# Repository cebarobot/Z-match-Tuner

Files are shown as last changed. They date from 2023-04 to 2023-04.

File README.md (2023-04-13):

# Z-match Tuner
> An open source Z-match Tuner for QRP  
> 一个开源的用于 QRP 的 Z-match 天调



## File List 文件列表
* `Z-match manual.pdf` 中文说明书
* `Z-match chematic.pdf ` 原理图
* `z-match-2.zip` KiCad 工程文件
* `z-match-2-gerber.zip` Gerber 制板文件
* `z-match panel.eprj` 前后面板的 LCEDA 工程文件

## License
MIT LICENSE

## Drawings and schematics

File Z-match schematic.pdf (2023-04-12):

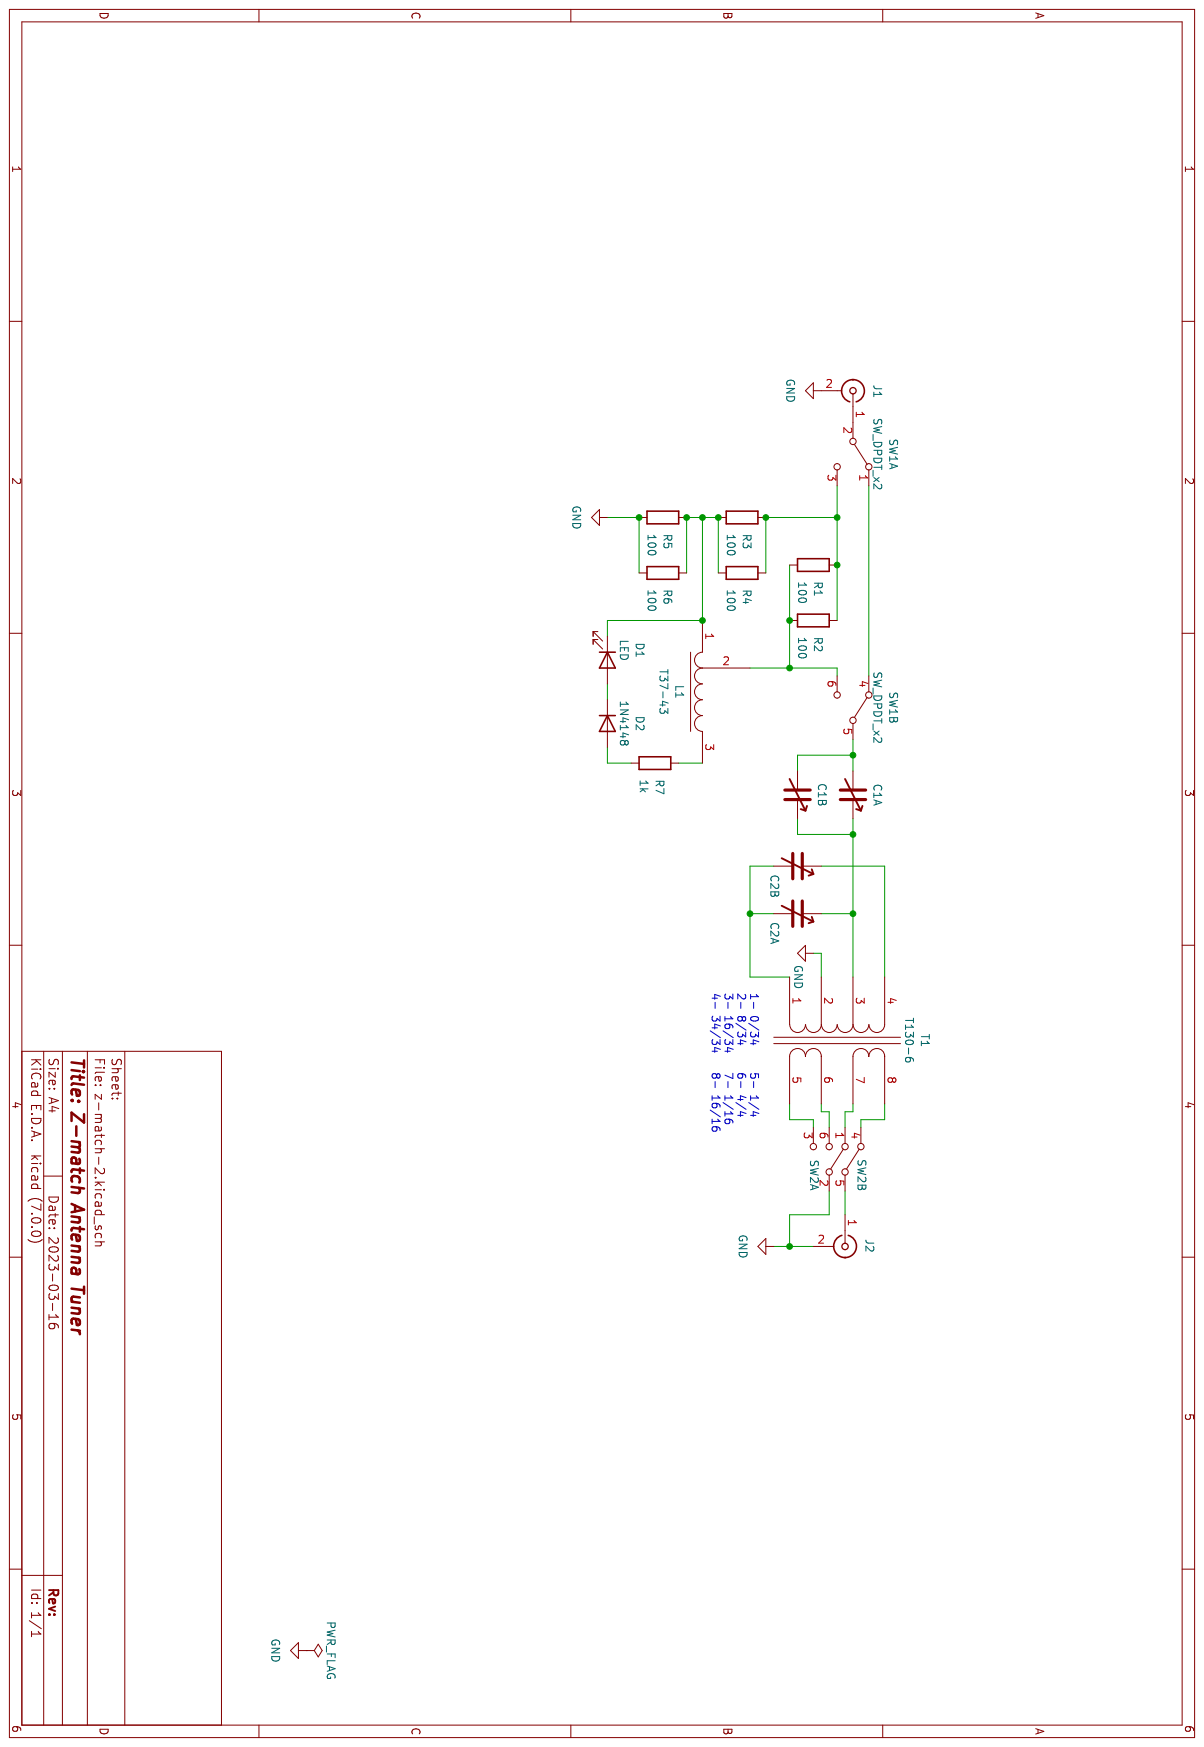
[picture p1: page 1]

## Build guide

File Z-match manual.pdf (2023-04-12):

Z-Match 套件安装使用手册

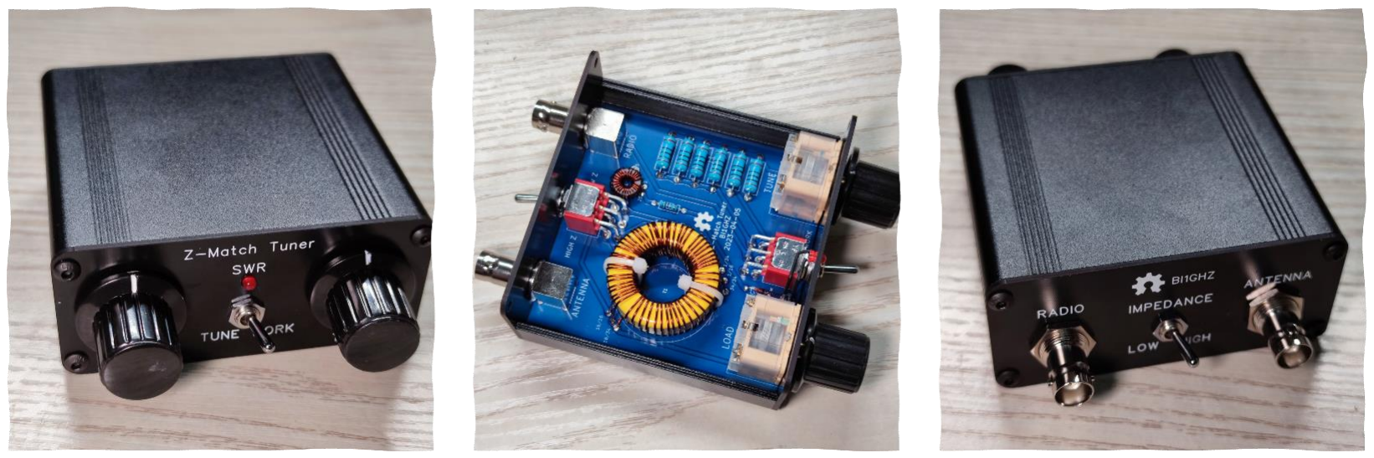
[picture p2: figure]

1 / 9

BI1GHZ 2023-04-13

### 零件表

检查 | 名称 | 数量 | 位号
| 可变电容 BM-443BF | 2 | C1, C2
| 加长杆 13mm | 2
| 螺丝 银色 圆头十字 M2.5×15mm | 2
| 螺丝 银色 沉头十字 M2.5×3 | 4
| 旋钮帽 KYP25-18-6 | 2
| 钮子开关 MT-0-202-A003-M003-RS | 2 | SW1, SW2
| 射频连接器 BNC-KWE 50R | 2 | J1, J2
| 电阻 1W 1% 100Ω | 6 | R1-6
| 电阻 1/4W 1% 1kΩ | 1 | R7
| 发光二极管 红色 3mm 长脚 | 1 | D1
| 二极管 1N4148 直插 | 1 | D2
| 环形铁氧体 FT37-43 | 1 | L1
| 环形铁氧体 T130-6 | 1 | L2
| 热缩管 Φ0.6 6cm | 1
| 扎带 3×80 | 2
| 漆包线 直径 0.4mm 长 60cm | 1
| 漆包线 直径 0.6mm 长 30cm | 1
| 漆包线 直径 0.6mm 长 50cm | 2
| 漆包线 直径 0.6mm 长 90cm | 1
| 漆包线 直径 0.6mm 长 100cm | 1
| PCB 蓝色 | 1
| 面板 FR-4 材质 黑色 88×38mm | 1 套
| 面板 铝合金 黑色 88×38mm | 1 套
| 机箱 铝合金 黑色 88×38×80mm | 1 套
| 螺丝 黑色 圆头内六角 M3×6 | 8
| 螺丝 黑色 沉头内六角 M3×6 | 8
| 简易套筒 10×55mm | 1

### 安装过程

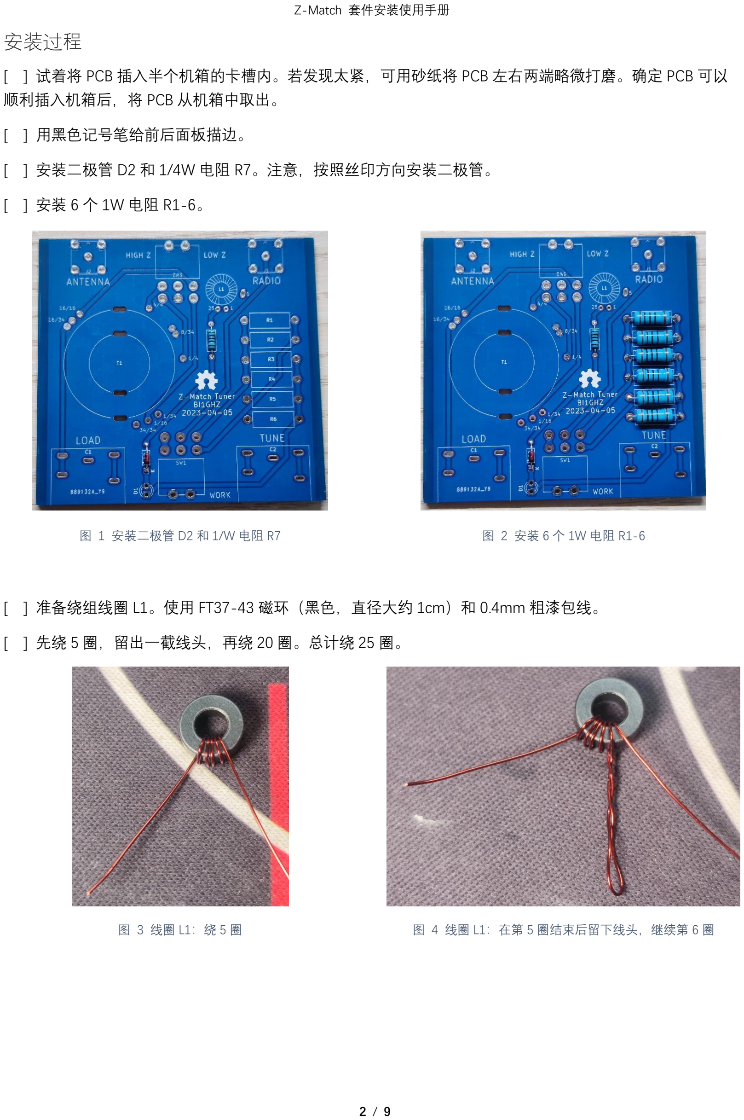
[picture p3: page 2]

2 / 9

[ ] 试着将 PCB 插入半个机箱的卡槽内。若发现太紧，可用砂纸将 PCB 左右两端略微打磨。确定 PCB 可以 顺利插入机箱后，将 PCB 从机箱中取出。

[ ] 用黑色记号笔给前后面板描边。

[ ] 安装二极管 D2 和 1/4W 电阻 R7。注意，按照丝印方向安装二极管。

[ ] 安装 6 个 1W 电阻 R1-6。

图 1 安装二极管 D2 和 1/W 电阻 R7 | 图 2 安装 6 个 1W 电阻 R1-6

[ ] 准备绕组线圈 L1。使用 FT37-43 磁环（黑色，直径大约 1cm）和 0.4mm 粗漆包线。

[ ] 先绕 5 圈，留出一截线头，再绕 20 圈。总计绕 25 圈。

图 3 线圈 L1：绕 5 圈 | 图 4 线圈 L1：在第 5 圈结束后留下线头，继续第 6 圈

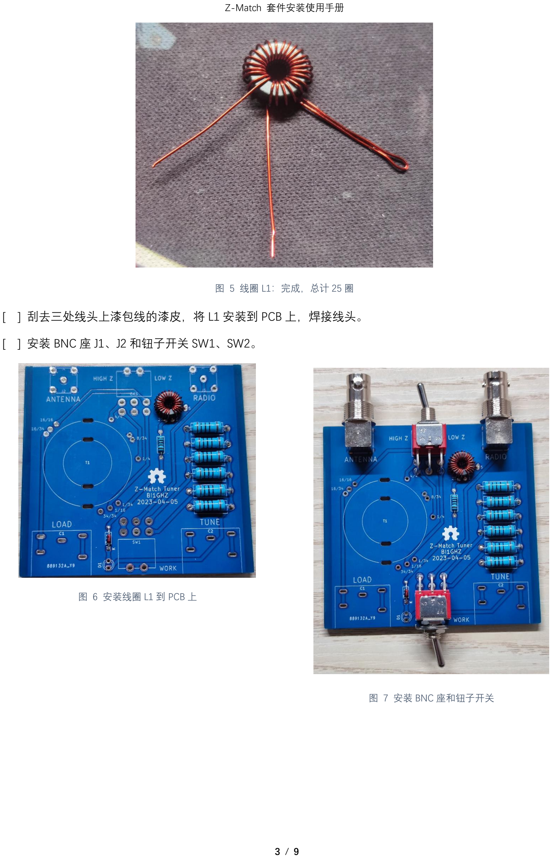
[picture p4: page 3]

3 / 9

图 5 线圈 L1：完成，总计 25 圈

[ ] 刮去三处线头上漆包线的漆皮，将 L1 安装到 PCB 上，焊接线头。

[ ] 安装 BNC 座 J1、J2 和钮子开关 SW1、SW2。

图 6 安装线圈 L1 到 PCB 上

图 7 安装 BNC 座和钮子开关

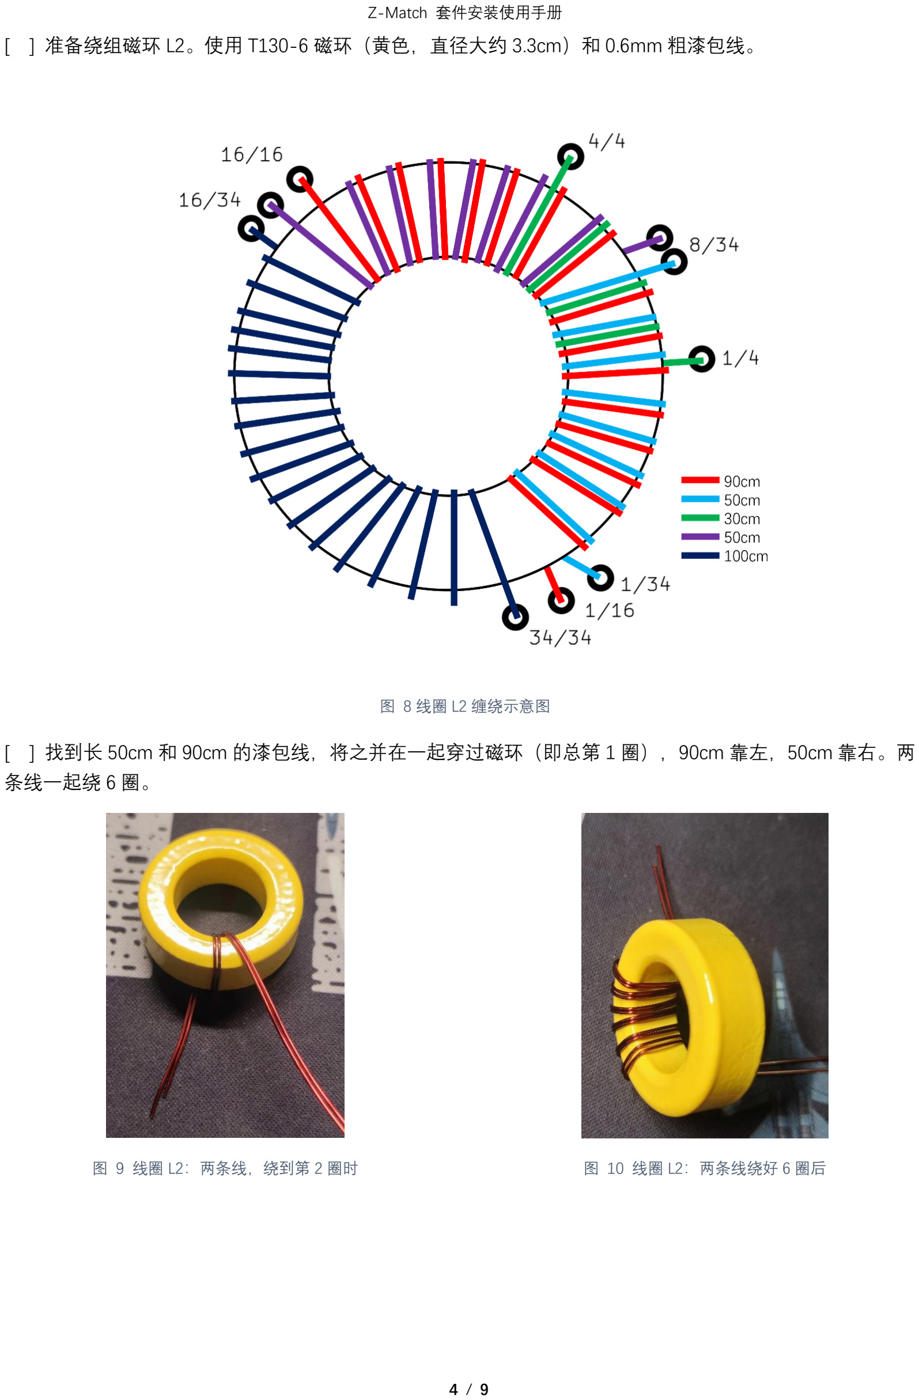
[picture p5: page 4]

4 / 9

[ ] 准备绕组磁环 L2。使用 T130-6 磁环（黄色，直径大约 3.3cm）和 0.6mm 粗漆包线。

图 8 线圈 L2 缠绕示意图

[ ] 找到长 50cm 和 90cm 的漆包线，将之并在一起穿过磁环（即总第 1 圈），90cm 靠左，50cm 靠右。两 条线一起绕 6 圈。

图 9 线圈 L2：两条线，绕到第 2 圈时 | 图 10 线圈 L2：两条线绕好 6 圈后

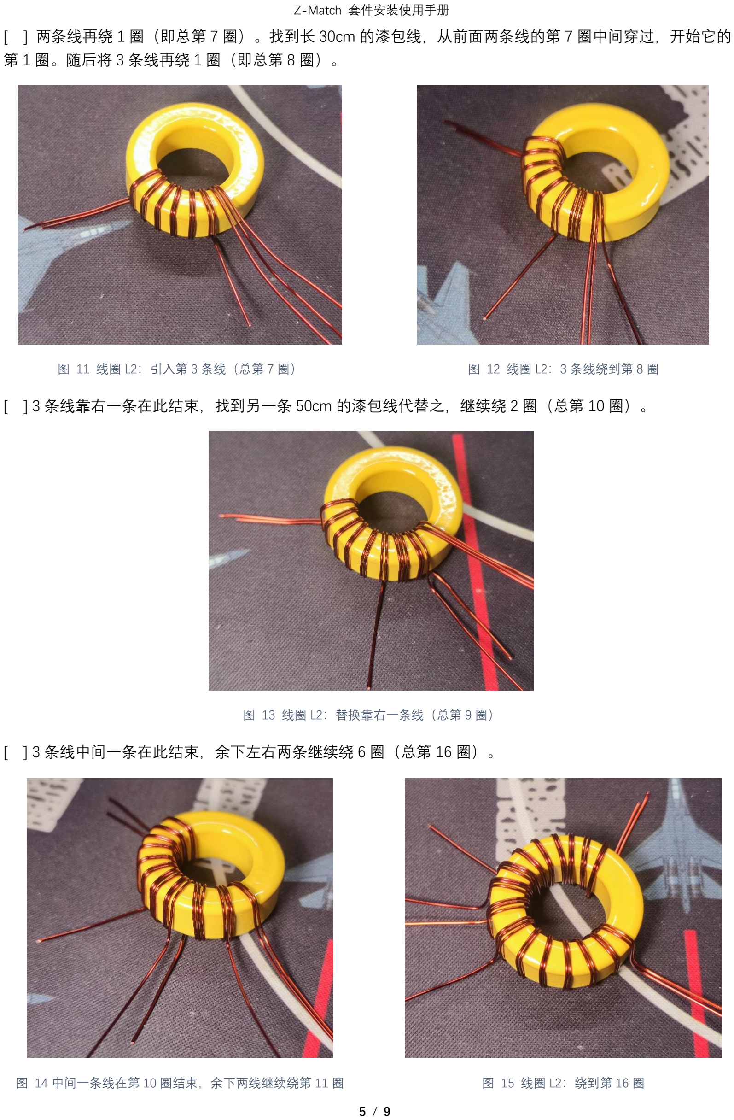
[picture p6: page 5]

5 / 9

[ ] 两条线再绕 1 圈（即总第 7 圈）。找到长 30cm 的漆包线，从前面两条线的第 7 圈中间穿过，开始它的 第 1 圈。随后将 3 条线再绕 1 圈（即总第 8 圈）。

图 11 线圈 L2：引入第 3 条线（总第 7 圈） | 图 12 线圈 L2：3 条线绕到第 8 圈

[ ] 3 条线靠右一条在此结束，找到另一条 50cm 的漆包线代替之，继续绕 2 圈（总第 10 圈）。

图 13 线圈 L2：替换靠右一条线（总第 9 圈）

[ ] 3 条线中间一条在此结束，余下左右两条继续绕 6 圈（总第 16 圈）。

图 14 中间一条线在第 10 圈结束，余下两线继续绕第 11 圈 | 图 15 线圈 L2：绕到第 16 圈

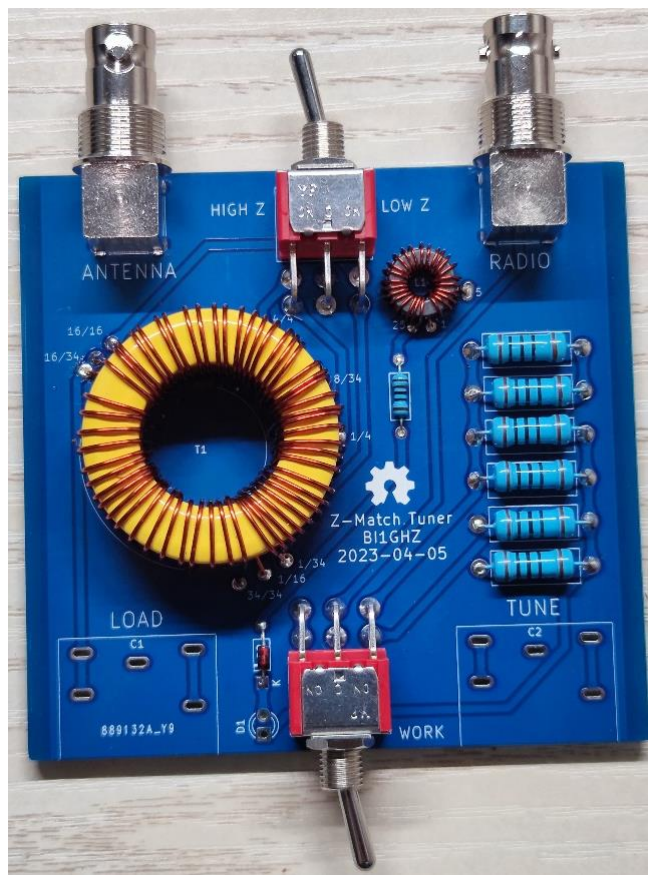
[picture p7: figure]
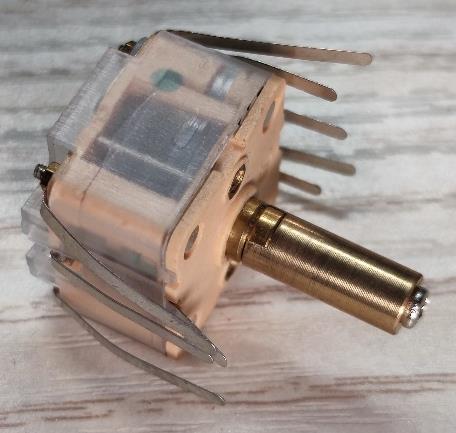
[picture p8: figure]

6 / 9

[ ] 2 条线均在此结束。找到 100cm 的漆包线，从此处开始绕 18 圈。

[ ] 刮去线头上漆包线的漆皮。将线头长度按逆时针或顺时针剪成阶梯状，以方便插入 PCB。

注意！在将 L2 安装到 PCB 前，务必进行目视检查，确保没有漆包线跨越缠绕；务必进行通铃检查，确保漆 包线头的顺序符合预期。

[ ] 将 L2 安装到 PCB 上，焊接接头。

图 16 将绕好的 L2 焊接到 PCB 上

[ ] 用扎带穿过安装孔，将磁环 L2 固定。

[ ] 将延长轴用 M2.5×12 螺丝固定到可调电容上。

图 17 安装好延长轴

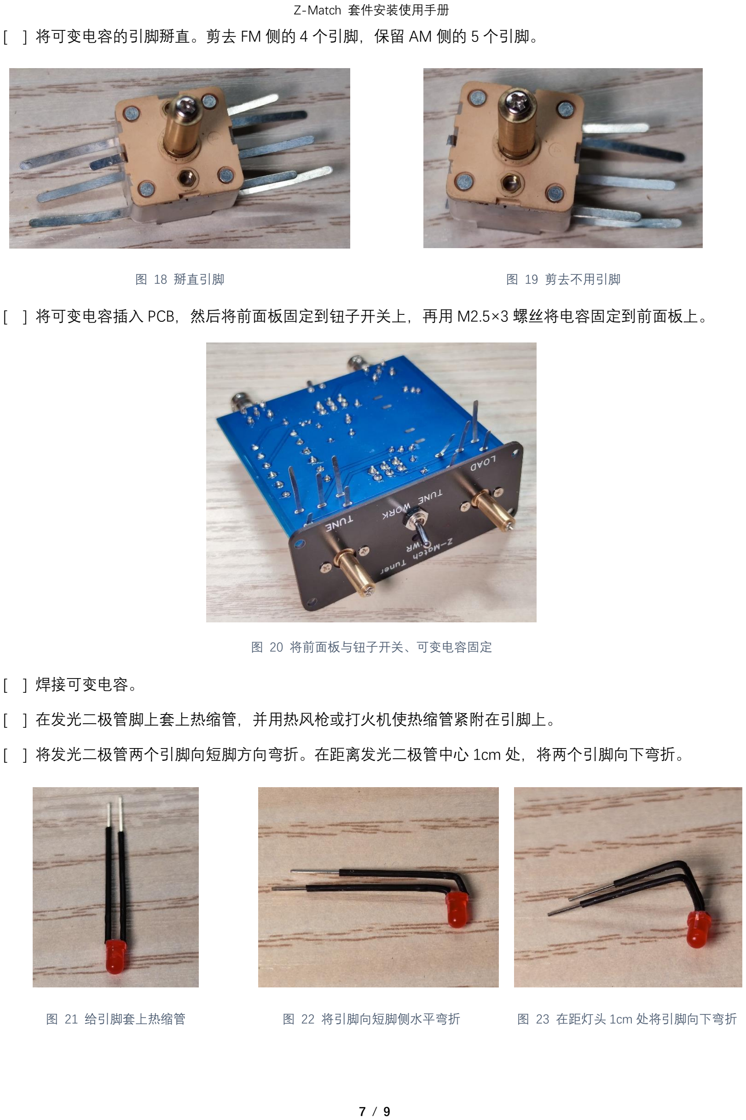
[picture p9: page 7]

7 / 9

[ ] 将可变电容的引脚掰直。剪去 FM 侧的 4 个引脚，保留 AM 侧的 5 个引脚。

图 18 掰直引脚 | 图 19 剪去不用引脚

[ ] 将可变电容插入 PCB，然后将前面板固定到钮子开关上，再用 M2.5×3 螺丝将电容固定到前面板上。

图 20 将前面板与钮子开关、可变电容固定

[ ] 焊接可变电容。

[ ] 在发光二极管脚上套上热缩管，并用热风枪或打火机使热缩管紧附在引脚上。

[ ] 将发光二极管两个引脚向短脚方向弯折。在距离发光二极管中心 1cm 处，将两个引脚向下弯折。

图 21 给引脚套上热缩管 | 图 22 将引脚向短脚侧水平弯折 | 图 23 在距灯头 1cm 处将引脚向下弯折

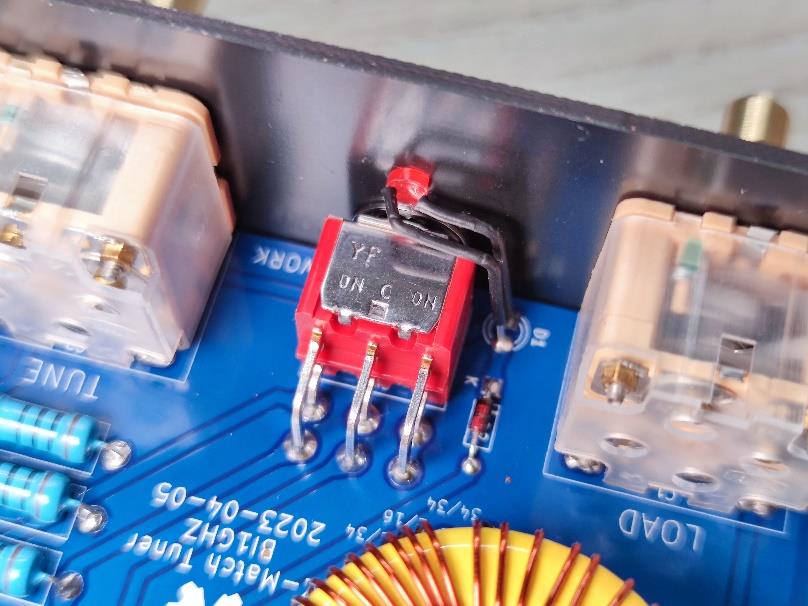
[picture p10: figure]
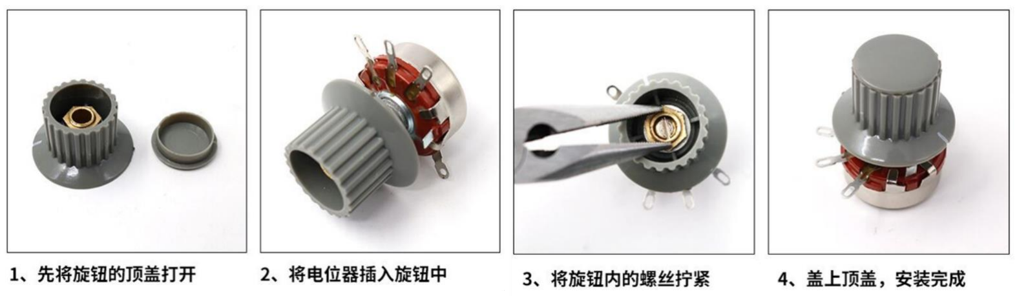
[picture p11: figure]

8 / 9

[ ] 将发光二极管穿过前面板上的洞，并焊接到 PCB 上。注意，短脚对方形焊盘。

图 24 安装好的 LED 示意

[ ] 将 PCB（和前面板）插入半个机箱中，将后面板、另半个机箱安装到位。将前后面板用 M3×6 圆头内六 角螺丝固定到机箱上，并将钮子开关、BNC 插座的螺母、可调电容的螺丝固定好。

提示：BNC 插座从内到外依次是 BNC 插座本体、面板、螺母，不使用垫片。

提示：钮子开关从内到外依次是钮子开关本体、螺母、垫片、面板、螺母，不使用固定片。

[ ] 去掉旋钮帽顶盖，将旋钮帽插入可调电容的轴上，而后用简易套筒将旋钮帽顶部螺母拧紧，盖回顶盖。 注意，可调电容的旋转角度为 180°，请在锁紧旋钮帽前调整好旋钮帽刻度线的方向。

图 25 安装旋钮帽的方法示意图

安装完成，赶快试试吧。

### 原理图

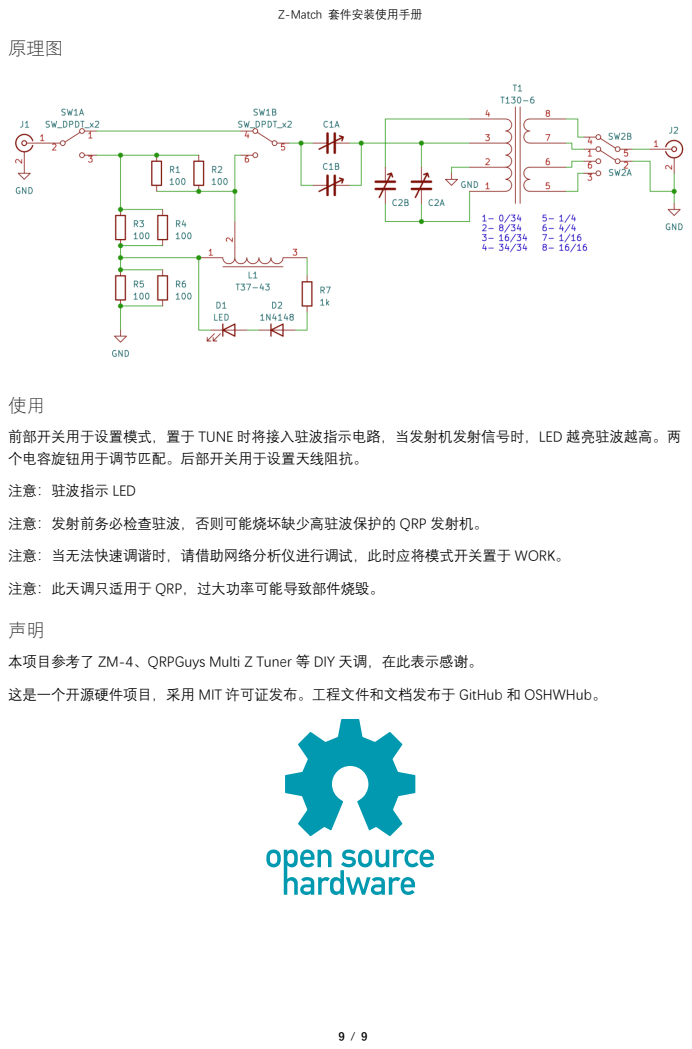
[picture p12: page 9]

前部开关用于设置模式，置于 TUNE 时将接入驻波指示电路，当发射机发射信号时，LED 越亮驻波越高。两
个电容旋钮用于调节匹配。后部开关用于设置天线阻抗。

注意：驻波指示 LED

注意：发射前务必检查驻波，否则可能烧坏缺少高驻波保护的 QRP 发射机。

注意：当无法快速调谐时，请借助网络分析仪进行调试，此时应将模式开关置于 WORK。

注意：此天调只适用于 QRP，过大功率可能导致部件烧毁。

本项目参考了 ZM-4、QRPGuys Multi Z Tuner 等 DIY 天调，在此表示感谢。

这是一个开源硬件项目，采用 MIT 许可证发布。工程文件和文档发布于 GitHub 和 OSHWHub。
